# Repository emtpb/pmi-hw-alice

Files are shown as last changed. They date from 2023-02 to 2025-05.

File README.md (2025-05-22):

# PMI Advanced Lights I2C Extension (ALICE)

This pcb is designed for the course PMI (Practical course Microcontroller
and Interface electronics) to model crossroads with traffic lights. It uses
an I2C port expander to drive several leds.

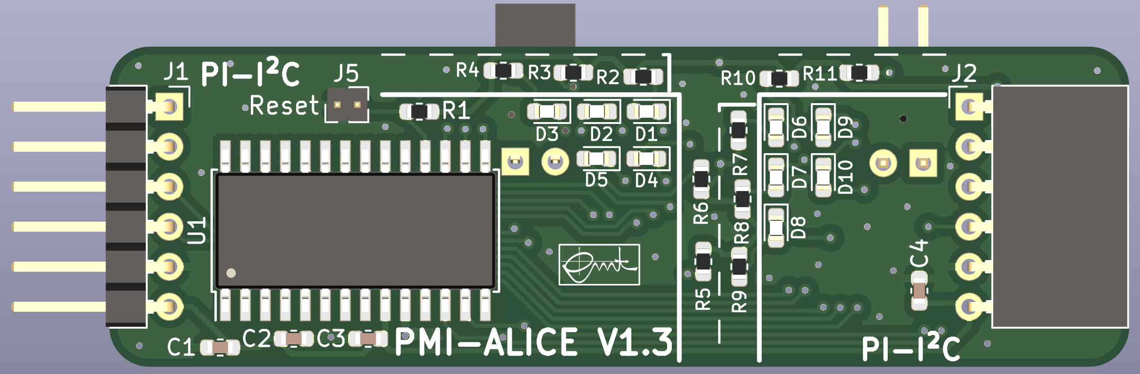
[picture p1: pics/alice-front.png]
ALICE-front


Pin header and sockets are compatible with
[Digilents Pmod](https://digilent.com/reference/pmod/start) interface.

The board can be used with [PMI's BoB²](https://github.com/emtpb/pmi-hw-bob2)
pcb.

# Interactive BOM

An interactive html BOM page with pcb layout and material placement can be found [here](https://emtpb.github.io/pmi-hw-alice/bom/ibom.html).

# Changelog

## 1.0
* First prototype

## 1.1
* First release

## 1.2
* Add reset bridge to be able to reset the ic at power up

## 1.3
* Convert project to Kicad 6
* Round pcb corners

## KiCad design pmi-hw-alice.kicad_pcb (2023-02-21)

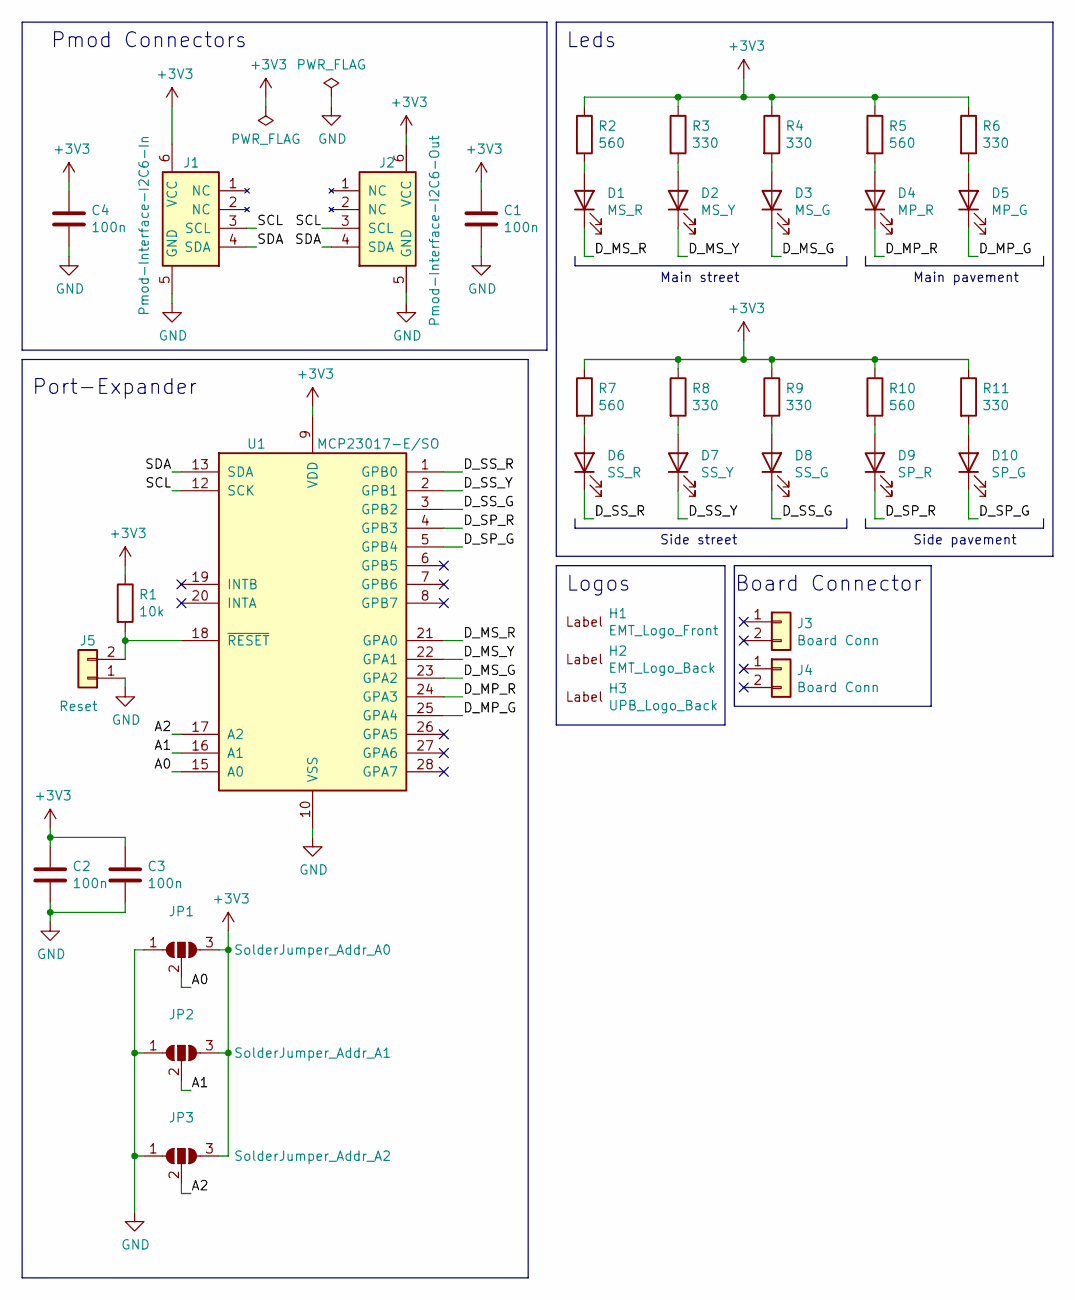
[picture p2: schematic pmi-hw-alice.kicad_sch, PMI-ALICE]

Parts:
C1, C2, C3, C4: 100n; C_0603_1608Metric
D1: MS_R; LED_0603_1608Metric; Manufacturer Part No LS L29K-G1H2-1-Z; Mouser Part No 720-LSL29K-G1H2-1-Z
D2: MS_Y; LED_0603_1608Metric; Manufacturer Part No LY L29K-H1K2-26; Mouser Part No 720-LYL29KH1K226Z
D3: MS_G; LED_0603_1608Metric; Manufacturer Part No LG L29K-F2J1-24-Z; Mouser Part No 720-LGL29KF2J124Z
D4: MP_R; LED_0603_1608Metric; Manufacturer Part No LS L29K-G1H2-1-Z; Mouser Part No 720-LSL29K-G1H2-1-Z
D5: MP_G; LED_0603_1608Metric; Manufacturer Part No LG L29K-F2J1-24-Z; Mouser Part No 720-LGL29KF2J124Z
D6: SS_R; LED_0603_1608Metric; Manufacturer Part No LS L29K-G1H2-1-Z; Mouser Part No 720-LSL29K-G1H2-1-Z
D7: SS_Y; LED_0603_1608Metric; Manufacturer Part No LY L29K-H1K2-26; Mouser Part No 720-LYL29KH1K226Z
D8: SS_G; LED_0603_1608Metric; Manufacturer Part No LG L29K-F2J1-24-Z; Mouser Part No 720-LGL29KF2J124Z
D9: SP_R; LED_0603_1608Metric; Manufacturer Part No LS L29K-G1H2-1-Z; Mouser Part No 720-LSL29K-G1H2-1-Z
D10: SP_G; LED_0603_1608Metric; Manufacturer Part No LG L29K-F2J1-24-Z; Mouser Part No 720-LGL29KF2J124Z
H1: EMT_Logo_Front; EMT-Logo_5.1x2.5mm_Silkscreen
H2: EMT_Logo_Back; EMT-Logo_8.2x4.1mm_Silkscreen
H3: UPB_Logo_Back; UPB-Logo_En_12.3X4.3mm
J1: Pmod-Interface-I2C6-In; Pmod_Interface_Male6
J2: Pmod-Interface-I2C6-Out; Pmod_Interface_Female6
J3: Board Conn; PinHeader_1x02_P2.54mm_Horizontal
J4: Board Conn; PinSocket_1x02_P2.54mm_Horizontal
J5: Reset; PinHeader_1x02_P1.27mm_Vertical
JP1: SolderJumper_Addr_A0; SolderJumper-3_P2.0mm_Open_TrianglePad1.0x1.5mm
JP2: SolderJumper_Addr_A1; SolderJumper-3_P2.0mm_Open_TrianglePad1.0x1.5mm
JP3: SolderJumper_Addr_A2; SolderJumper-3_P2.0mm_Open_TrianglePad1.0x1.5mm
R1: 10k; R_0603_1608Metric
R2, R5, R7, R10: 560; R_0603_1608Metric
R3, R4, R6, R8, R9, R11: 330; R_0603_1608Metric
U1: MCP23017-E/SO; SOIC-28W_7.5x17.9mm_P1.27mm; Mouser Part No 579-MCP23017-E/SO

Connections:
+3V3: C1.1, C2.1, C3.1, C4.1, J1.6 (VCC), J2.6 (VCC), JP1.3 (B), JP2.3 (B), JP3.3 (B), R1.1, R2.1, R3.1, R4.1, R5.1, R6.1, R7.1, R8.1, R9.1, R10.1, R11.1, U1.9 (VDD)
/A0: JP1.2 (C), U1.15 (A0)
/A1: JP2.2 (C), U1.16 (A1)
/A2: JP3.2 (C), U1.17 (A2)
/D_MP_G: D5.1 (K), U1.25 (GPA4)
/D_MP_R: D4.1 (K), U1.24 (GPA3)
/D_MS_G: D3.1 (K), U1.23 (GPA2)
/D_MS_R: D1.1 (K), U1.21 (GPA0)
/D_MS_Y: D2.1 (K), U1.22 (GPA1)
/D_SP_G: D10.1 (K), U1.5 (GPB4)
/D_SP_R: D9.1 (K), U1.4 (GPB3)
/D_SS_G: D8.1 (K), U1.3 (GPB2)
/D_SS_R: D6.1 (K), U1.1 (GPB0)
/D_SS_Y: D7.1 (K), U1.2 (GPB1)
/SCL: J1.3 (SCL), J2.3 (SCL), U1.12 (SCK)
/SDA: J1.4 (SDA), J2.4 (SDA), U1.13 (SDA)
GND: C1.2, C2.2, C3.2, C4.2, J1.5 (GND), J2.5 (GND), J5.1, JP1.1 (A), JP2.1 (A), JP3.1 (A), U1.10 (VSS)
unnamed: D1.2 (A), R2.2
unnamed: D2.2 (A), R3.2
unnamed: D3.2 (A), R4.2
unnamed: D4.2 (A), R5.2
unnamed: D5.2 (A), R6.2
unnamed: D6.2 (A), R7.2
unnamed: D7.2 (A), R8.2
unnamed: D8.2 (A), R9.2
unnamed: D9.2 (A), R10.2
unnamed: D10.2 (A), R11.2
unnamed: J5.2, R1.2, U1.18 (~RESET)

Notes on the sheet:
Main pavement
Main street
Side pavement
Leds
Side street
Pmod Connectors
Port-Expander
Board Connector
Logos

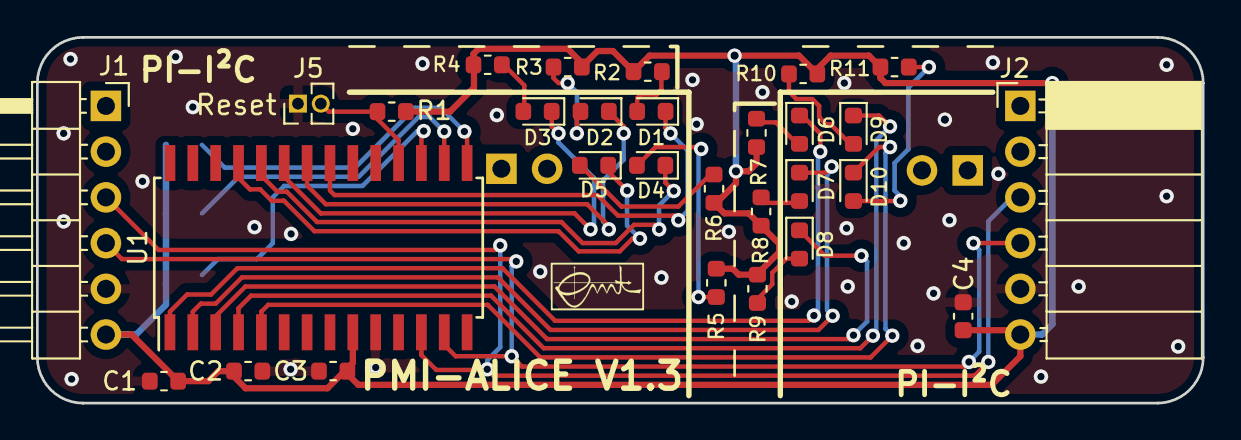
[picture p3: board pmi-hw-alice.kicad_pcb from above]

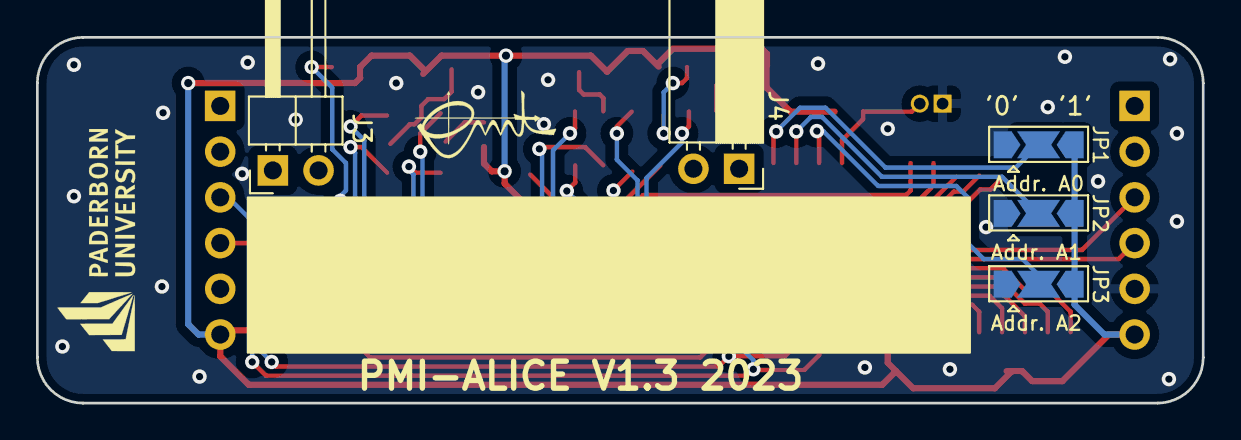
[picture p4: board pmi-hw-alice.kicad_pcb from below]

Board: 2 copper layers, 64.8 x 20.3 mm, 37 parts (7 on the bottom side), 28 nets.

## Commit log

2021-12-21 Initial revision
    [pmi-hw-alice.kicad_pcb, pmi-hw-alice.sch]
2021-12-23 Bump to V1.2
    * Add reset bridge to be able to reset the ic at power up
    [pmi-hw-alice.kicad_pcb, pmi-hw-alice.sch]
2023-02-21 Bump to V1.3
    [pmi-hw-alice.kicad_pcb, pmi-hw-alice.kicad_sch, pmi-hw-alice.sch]
2025-05-22 Add interactive BOM link
